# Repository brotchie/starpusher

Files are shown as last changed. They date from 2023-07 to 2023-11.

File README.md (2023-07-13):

# Starpusher

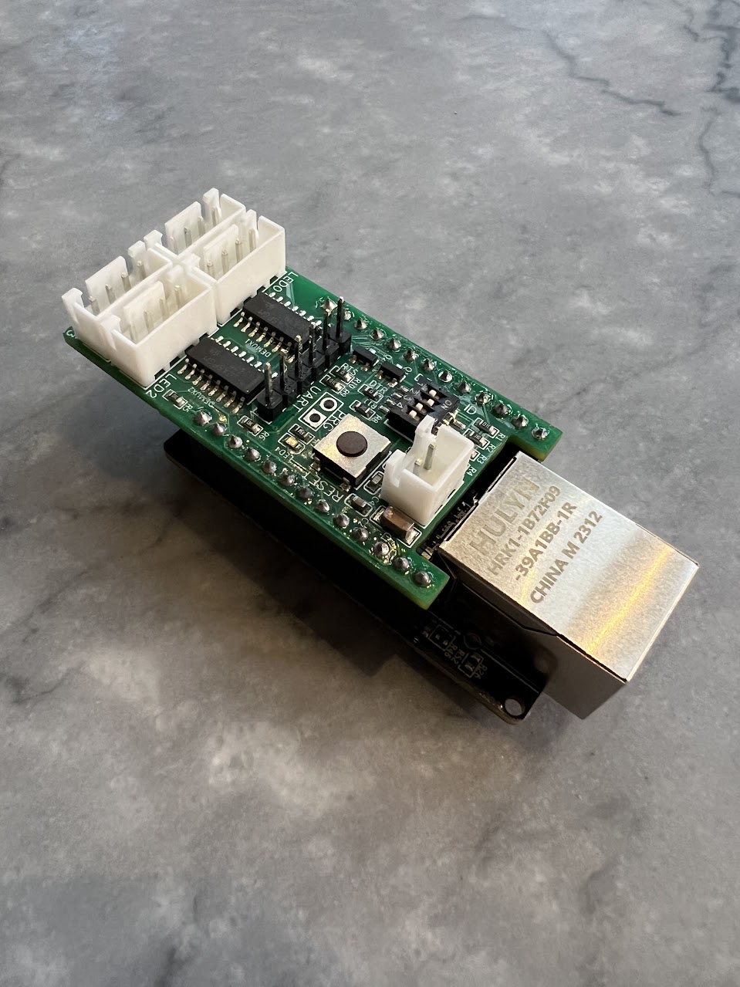
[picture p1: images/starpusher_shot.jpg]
Starshield


A Starpusher controls 4 x strips of APA102 LEDs (up to 420 LEDs per strip), taking LED information via UDP ethernet packets. We've tested it to run 4 x 420 LED strips at 60FPS with no glitches.

A Starpush comprises a [WT32 ETH01](https://www.amazon.com/EC-Buying-WT32-ETH01-Development-Bluetooth/dp/B09Z298QJQ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) with a custom-designed Starshield. The Starshield has a DIP switch that configures the Static IP address a given Starpusher uses and has headers for 4 LED strips.

See the comments in [main/starpusher.c](main/starpusher.c) for a codebase guide.

## Development Environment
Starshield code is built using the esp-idf toolchain.

1. Follow the steps in the [Standard Toolchain Setup Guide](https://docs.espressif.com/projects/esp-idf/en/latest/esp32/get-started/linux-macos-setup.html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),
2. Activate the esp-idf environment in a terminal (typically `$ get_idf` after following the setup guide,
3. Build the codebase `$ idf.py build`,
4. Connect your Starshield PCB to a WT32 ETH01 base board,
5. Connect a USB UART to the UART header on the Starshield,
6. Flash the Starpusher code onto the WT32 ETH01 by running `$ idf.py -p /dev/ttyUSB0 flash`
7. Monitor the WT32 ETH01's logs by running `$ idf.py -p /dev/ttyUSB0 monitor`

## REQUIRED: Configuring a new WT32 ETH01 for Starshield use
By default, on bootup, an ESP32 uses the value of pin IO12 to determine SPI Flash chip voltage. It has an internal pull-down so defaults to low (3.3V flash chip). If held high during bootup, then ESP32 treats Flash Chip voltage as 1.8V.

On our board we have a pull-up on IO12 since it's used to set the device ID via dip switch. The fix is to blow an eFuse on the ESP32 that fixes Flash chip voltage to 3.3v.

Do the following:

1. Set all dip switches on the ON position (this pulls IO12 low so it will actually boot), 
2. Run the following command to permanently burn the eFuse governing flash voltage so it's forced to 3.3V
   \
   `$ espefuse.py --do-not-confirm --port /dev/ttyUSBx set_flash_voltage 3.3V`
   \
   Replacing `/dev/ttyUSBx` with the port of your USB tty.

## Starshield

Schematics, gerber, BOM, and pick-and-place data for the Starshield V2 is in the `starshield` sub-folder.

### Board Overview

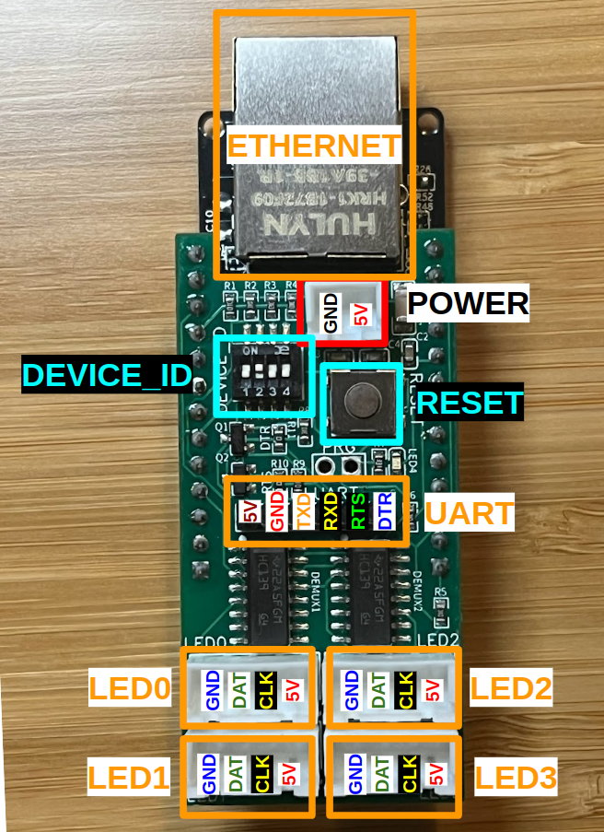
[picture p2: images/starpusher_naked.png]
Starshield Naked


### UART

The WT32 ETH01 that the Starshield sits sits on can be progammed via a USB UART (all development was done with a [DSD TECH SH-U09C5](https://www.amazon.com/gp/product/B07WX2DSVB/)) which has RTS and DTR pins so that ESP-IDF can program the ESP32 without having to manually fiddle with jumpers / manual resets.

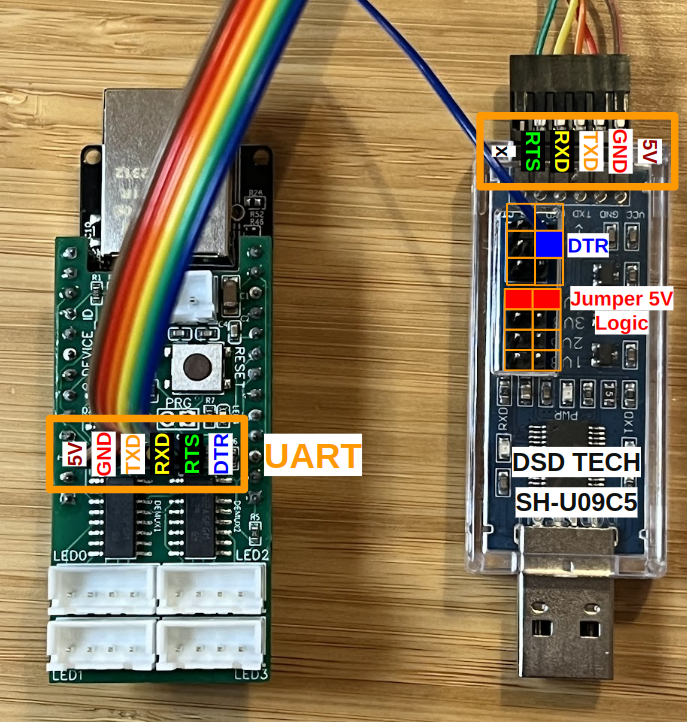
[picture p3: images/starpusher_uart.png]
Starshield UART


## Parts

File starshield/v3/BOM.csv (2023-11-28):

ID | Name | Designator | Footprint | Quantity | Manufacturer Part | Manufacturer | Supplier | Supplier Part | Price
1 | HDR-M-2.54_1x3 | BTNS | HDR-M-2.54_1X3 | 1 |  |  | LCSC | C180248 | 0.199
2 | 10kΩ | R12,R13,R1,R2,R3,R4,R6,R7,R10,R11 | R0402 | 10 | 0402WGF1002TCE | UNI-ROYAL(厚声) | LCSC | C25744 | 0.001
3 | XY303V-3.81-3P | PORT1,PORT2,PORT3,PORT4,PORT5,PORT6,PORT7,PORT8 | CONN-TH_XY303V-3.81-3P | 8 | XY303V-3.81-3P | XINLAIYA(新莱亚) | LCSC | C557684 | 0.168
4 | XY303V-3.81-2P | 12V | CONN-TH_XY303V-3.81-2P | 1 | XY303V-3.81-2P | XINLAIYA(新莱亚) | LCSC | C557683 | 0.113
5 | CD4504BM96 | LS1,LS2 | SOIC-16_L9.9-W3.9-P1.27-LS6.0-BL | 2 | CD4504BM96 | TI(德州仪器) | LCSC | C151885 | 0.395
6 | SN74HC595PWR | SR1,SR2 | TSSOP-16_L5.0-W4.4-P0.65-LS6.4-BL | 2 | SN74HC595PWR | TI(德州仪器) | LCSC | C273642 | 0.29
7 | 74HC165D,653 | SRID | SOIC-16_L9.9-W3.9-P1.27-LS6.0-BL | 1 | 74HC165D,653 | Nexperia(安世) | LCSC | C5613 | 0.155
8 | XL-5050RGBC-WS2812B | LED1 | LED-SMD_4P-L5.0-W5.0-BL_XL-5050RGBC | 1 | XL-5050RGBC-WS2812B | XINGLIGHT(成兴光) | LCSC | C2843785 | 0.044
9 | 1nF | C6 | C0402 | 1 | CC0402KRX7R9BB102 | YAGEO(国巨) | LCSC | C106205 | 0.001
10 | MT2492 | U6 | SOT-23-6_L2.9-W1.6-P0.95-LS2.8-BL | 1 | MT2492 | 西安航天民芯 | LCSC | C89358 | 0.051
11 | 22pF | BC1 | C0402 | 1 | 0402CG220J500NT | FH(风华) | LCSC | C1555 | 0.001
12 | 10uH | BL | IND-SMD_L4.4-W4.2 | 1 | FXL0420-100-M | cjiang(长江微电) | LCSC | C177242 | 0.111
13 | 110kΩ | BR1 | R0402 | 1 | RCT02110KJLF | HKR | LCSC | C174165
14 | 15kΩ | BR2 | R0402 | 1 | RMCF0402FT15K0 | SEI(Stackpole Electronics Inc.) | LCSC | C237741 | 0.003
15 | 22nF | BC2 | C0402 | 1 | CC0402KRX7R9BB223 | YAGEO(国巨) | LCSC | C107026 | 0.002
16 | 22uF | BCIN,BCOUT1,BCOUT2 | C0805 | 3 | CL21A226MAQNNNE | SAMSUNG(三星) | LCSC | C45783 | 0.026
17 | DSHP08TSGER_C3293147 | SW1 | SW-SMD_16P-L11.7-W5.4-P1.27-LS8.5 | 1 | DSHP08TSGER | 康深 | LCSC | C3293147 | 0.581
18 | Header-Male-2.54_1x6 | UART | HDR-TH_6P-P2.54-V-M-1 | 1 | 2.54-1x6P直针 | BOOMELE(博穆精密) | LCSC | C37208 | 0.028
19 | DTSL-61N-V-T/R | RESET | SW-SMD_4P-L6.2-W6.4-P4.00-LS7.2 | 1 | DTSL-61N-V-T/R | 圜达 | LCSC | C495902 | 0.055
20 | 10kΩ | R5,R8,R9 | R0603 | 3 | 0603WAF1002T5E | UNI-ROYAL(厚声) | LCSC | C25804 | 0.001
21 | MMBT2222A_C411776 | Q1,Q2 | SOT-23_L2.9-W1.3-P1.90-LS2.4-BR | 2 | MMBT2222A | PJSEMI(平晶微) | LCSC | C411776 | 0.019
22 | PM254-1-13-Z-8.5 | SH1,SH2 | HDR-TH_13P-P2.54-V-F | 2 | PM254-1-13-Z-8.5 | HCTL(华灿天禄) | LCSC | C2897376 | 0.204

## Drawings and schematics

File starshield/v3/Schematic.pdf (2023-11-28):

## Flash Circuit

## 12V to 5V Buck

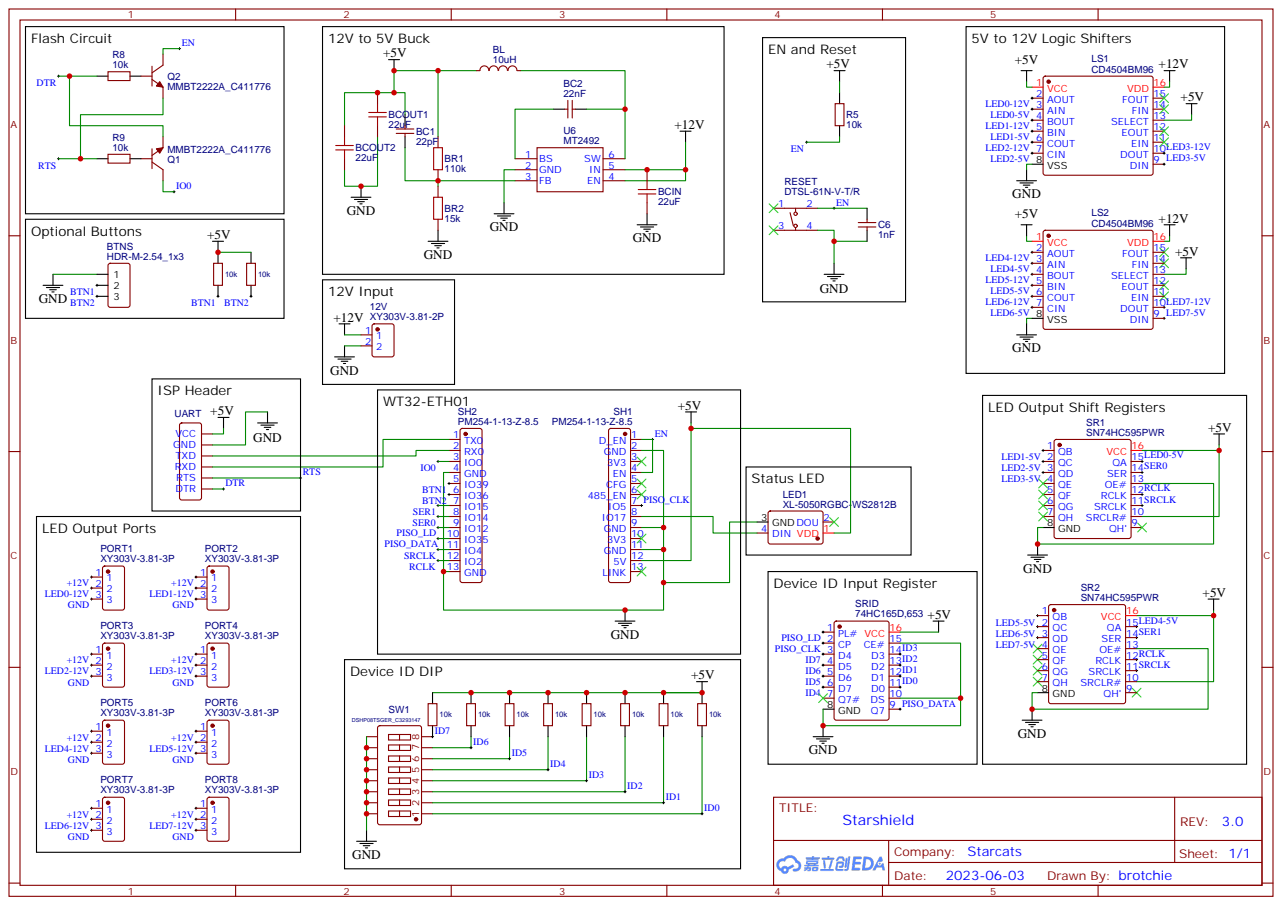
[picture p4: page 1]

LED Output Shift Registers

Device ID Input Register
DS 10 D0 11 D1 12 D2 13 D3 14 CE# 15 VCC 16

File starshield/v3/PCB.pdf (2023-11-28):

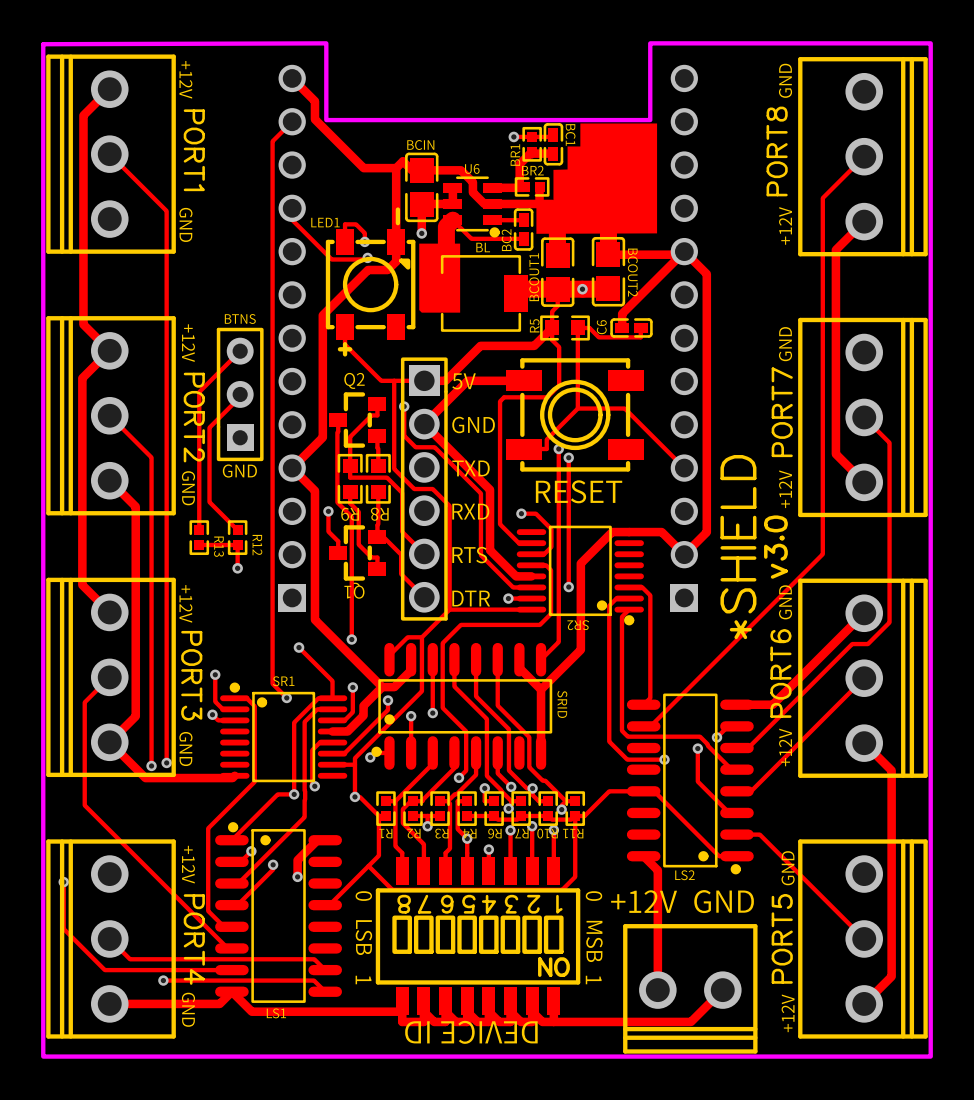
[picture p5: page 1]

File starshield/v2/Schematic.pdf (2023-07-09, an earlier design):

# 2Y2 10 2Y1 11 2Y0 12 2B 13 2A 14 2G# 15 VCC 16

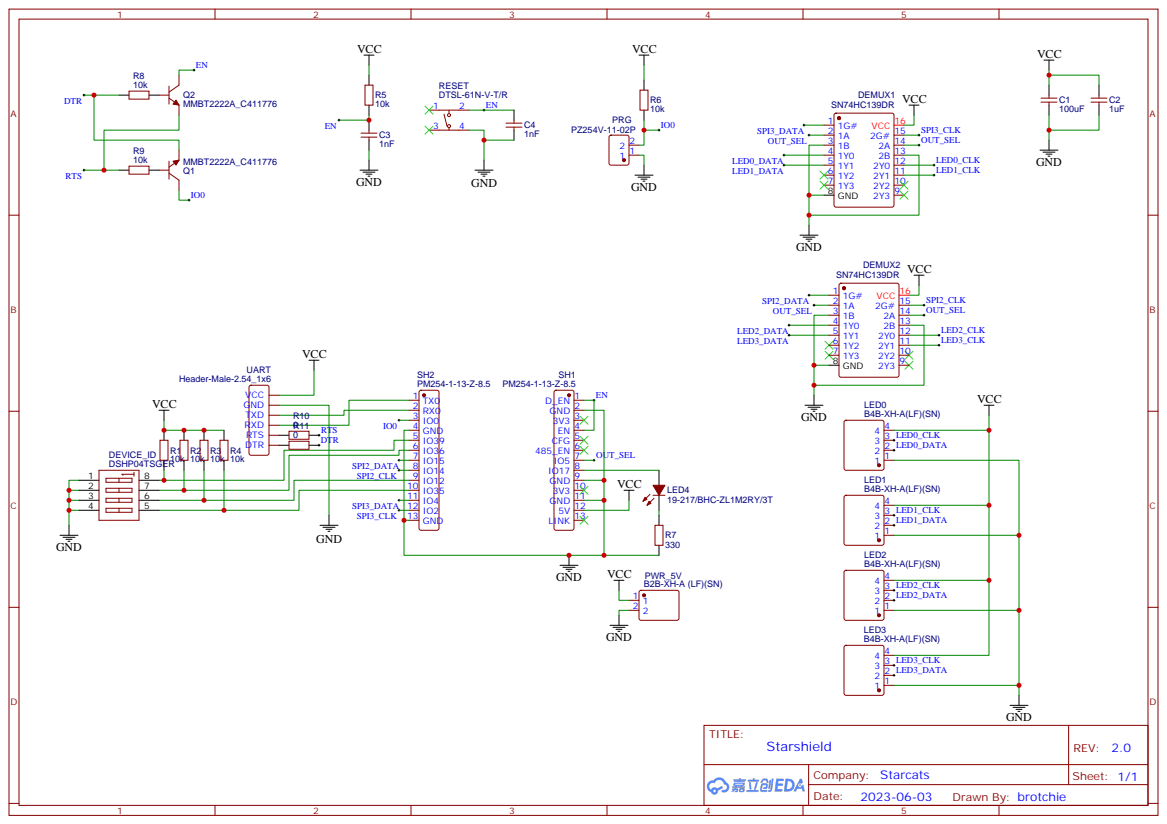
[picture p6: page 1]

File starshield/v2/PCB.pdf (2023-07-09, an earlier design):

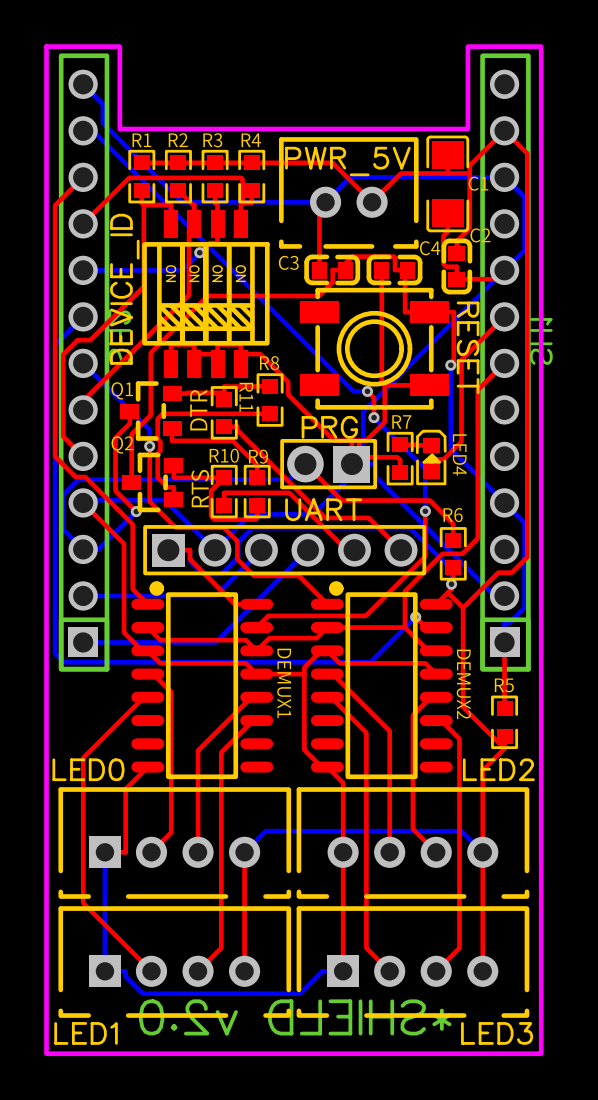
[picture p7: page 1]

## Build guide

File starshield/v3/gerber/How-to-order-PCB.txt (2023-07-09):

How to Order PCB

Please refer to:
https://docs.easyeda.com/en/PCB/Order-PCB

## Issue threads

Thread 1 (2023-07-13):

Add rainbow chase pattern for device id 14

brotchie, 2023-07-13:
Device id 15 is all white output, set device id 14 to be a 60 FPS rainbow chase to test changing pixel values.

When debugging attached LED strips it's valuable to see how they handle all-white at full intensity, but also how they handle full brightness patterns changing at a high rate with every pixel lit.

Closed 2023-11-27.

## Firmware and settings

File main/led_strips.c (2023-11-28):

#include <inttypes.h>
#include <string.h>

#include <driver/gpio.h>
#include <driver/spi_master.h>
#include <esp_heap_caps.h>
#include <esp_intr_alloc.h>
#include <esp_log.h>
#include <esp_timer.h>
#include <freertos/FreeRTOS.h>
#include <freertos/semphr.h>
#include <freertos/task.h>
#include <freertos/timers.h>

#include "color.h"
#include "led_strips.h"

static const char *TAG = "led_strips";

//#define BUILT_IN_ANIMATIONS
//#define PRINT_TIMING_DEBUG

#define PORT_COUNT 8

// 3 triangles with 55 LEDs on each side.
#define LEDS_PER_PORT 9 * 55

#define SPI_MAX_TRANSFER_SIZE 71282

// Drive SPI clock at 11Mhz. At 13Mhz it starts to glitch
// out a LED strip of length 495. At 10MHz is doesn't fit
// in the 13.3ms time bound for 60FPS.
#define SR_SRCLK_FREQUENCY SPI_MASTER_FREQ_11M

#define SR_SRCLK_GPIO GPIO_NUM_4

#define SR_SER0_GPIO GPIO_NUM_14
#define SR_SER1_GPIO GPIO_NUM_15
#define SR_RCLK_GPIO GPIO_NUM_2
// Unfortunately the SPI driver won't work in QUAD mode
// without mapping the data3 pin through GPIO (maybe
// there's a way around this?). We simply map the 4th
// SPI line to the CFG pin on the WT32-ETH0, which I
// don't think is used for anything.
#define SR_ZERO_GPIO GPIO_NUM_32

#define SR_SPI_HOST SPI2_HOST

static rgb_t pixel_buffer[PORT_COUNT][LEDS_PER_PORT];
static SemaphoreHandle_t pixel_buffer_mutex;

static spi_device_handle_t spi;
static uint8_t *dma_buffer = NULL;
static size_t dma_buffer_size;

static TaskHandle_t led_update_task_handle;

static TickType_t led_update_frequency = 60;

static uint32_t led_strips_animation_cycle = 0;

static uint64_t total_time_spent = 0;

void led_strips_spi_bus_initialize() {
  esp_err_t ret;
  spi_bus_config_t buscfg = {
      .data0_io_num = SR_RCLK_GPIO,
      .data1_io_num = SR_SER0_GPIO,
      .data2_io_num = SR_SER1_GPIO,
      .data3_io_num = SR_ZERO_GPIO,
      .sclk_io_num = SR_SRCLK_GPIO,
      .flags = SPICOMMON_BUSFLAG_QUAD | SPICOMMON_BUSFLAG_MASTER,
      .max_transfer_sz = SPI_MAX_TRANSFER_SIZE,
      // Pin all SPI ISR handling on CPU core 1.
      .isr_cpu_id = INTR_CPU_ID_1,
  };
  ret = spi_bus_initialize(SR_SPI_HOST, &buscfg, SPI_DMA_CH_AUTO);
  ESP_ERROR_CHECK(ret);

  spi_device_interface_config_t devcfg = {
      .clock_speed_hz = SR_SRCLK_FREQUENCY,
      .spics_io_num = -1,
      .queue_size = 1,
      // Don't need to receive SPI.
      .flags = SPI_DEVICE_HALFDUPLEX,
  };
  ret = spi_bus_add_device(SR_SPI_HOST, &devcfg, &spi);
  ESP_ERROR_CHECK(ret);
}

void led_strips_animation_tick() {
  for (uint16_t index = 0; index < LEDS_PER_PORT; index++) {
    rgb_t color = hsv_to_rgb(
        ((index + led_strips_animation_cycle) % 255) / 255.0f, 1.0, 1.0);
    for (uint8_t port = 0; port < PORT_COUNT; port++) {
      pixel_buffer[port][index] = color;
    }
  }
}

// Here we've pre-calculated the interleaving of all possible bytes into the
// packed format for quad-SPI DMA. This trades off memory (512 bytes) to save
// a bunch of shift and masking operations.
//
// These values also include bits for the shift register clock signal on SPI
// DATA0 and the empty last channel of quad-SPI on SPI DATA3.
static const uint16_t interleave_table_little_endian[256] = {
    0x0010, 0x0410, 0x4010, 0x4410, 0x0014, 0x0414, 0x4014, 0x4414, 0x0050,
    0x0450, 0x4050, 0x4450, 0x0054, 0x0454, 0x4054, 0x4454, 0x0210, 0x0610,
    0x4210, 0x4610, 0x0214, 0x0614, 0x4214, 0x4614, 0x0250, 0x0650, 0x4250,
    0x4650, 0x0254, 0x0654, 0x4254, 0x4654, 0x2010, 0x2410, 0x6010, 0x6410,
    0x2014, 0x2414, 0x6014, 0x6414, 0x2050, 0x2450, 0x6050, 0x6450, 0x2054,
    0x2454, 0x6054, 0x6454, 0x2210, 0x2610, 0x6210, 0x6610, 0x2214, 0x2614,
    0x6214, 0x6614, 0x2250, 0x2650, 0x6250, 0x6650, 0x2254, 0x2654, 0x6254,
    0x6654, 0x0012, 0x0412, 0x4012, 0x4412, 0x0016, 0x0416, 0x4016, 0x4416,
    0x0052, 0x0452, 0x4052, 0x4452, 0x0056, 0x0456, 0x4056, 0x4456, 0x0212,
    0x0612, 0x4212, 0x4612, 0x0216, 0x0616, 0x4216, 0x4616, 0x0252, 0x0652,
    0x4252, 0x4652, 0x0256, 0x0656, 0x4256, 0x4656, 0x2012, 0x2412, 0x6012,
    0x6412, 0x2016, 0x2416, 0x6016, 0x6416, 0x2052, 0x2452, 0x6052, 0x6452,
    0x2056, 0x2456, 0x6056, 0x6456, 0x2212, 0x2612, 0x6212, 0x6612, 0x2216,
    0x2616, 0x6216, 0x6616, 0x2252, 0x2652, 0x6252, 0x6652, 0x2256, 0x2656,
    0x6256, 0x6656, 0x0030, 0x0430, 0x4030, 0x4430, 0x0034, 0x0434, 0x4034,
    0x4434, 0x0070, 0x0470, 0x4070, 0x4470, 0x0074, 0x0474, 0x4074, 0x4474,
    0x0230, 0x0630, 0x4230, 0x4630, 0x0234, 0x0634, 0x4234, 0x4634, 0x0270,
    0x0670, 0x4270, 0x4670, 0x0274, 0x0674, 0x4274, 0x4674, 0x2030, 0x2430,
    0x6030, 0x6430, 0x2034, 0x2434, 0x6034, 0x6434, 0x2070, 0x2470, 0x6070,
    0x6470, 0x2074, 0x2474, 0x6074, 0x6474, 0x2230, 0x2630, 0x6230, 0x6630,
    0x2234, 0x2634, 0x6234, 0x6634, 0x2270, 0x2670, 0x6270, 0x6670, 0x2274,
    0x2674, 0x6274, 0x6674, 0x0032, 0x0432, 0x4032, 0x4432, 0x0036, 0x0436,
    0x4036, 0x4436, 0x0072, 0x0472, 0x4072, 0x4472, 0x0076, 0x0476, 0x4076,
    0x4476, 0x0232, 0x0632, 0x4232, 0x4632, 0x0236, 0x0636, 0x4236, 0x4636,
    0x0272, 0x0672, 0x4272, 0x4672, 0x0276, 0x0676, 0x4276, 0x4676, 0x2032,
    0x2432, 0x6032, 0x6432, 0x2036, 0x2436, 0x6036, 0x6436, 0x2072, 0x2472,
    0x6072, 0x6472, 0x2076, 0x2476, 0x6076, 0x6476, 0x2232, 0x2632, 0x6232,
    0x6632, 0x2236, 0x2636, 0x6236, 0x6636, 0x2272, 0x2672, 0x6272, 0x6672,
    0x2276, 0x2676, 0x6276, 0x6676};

#define INTERLEAVE(q, out)                                                     \
  *(uint16_t *)(out) = interleave_table_little_endian[q];

void init_dma_buffer(uint8_t *out, size_t count) {
  // Only the middle bit of each physical bit on the wire changes. The
  // first and last bit are always 1 and 0 respectively.
  for (size_t i = 0; i < 3 * count; i++) {
    INTERLEAVE(0xff, out);
    out += 2;
    INTERLEAVE(0x00, out);
    out += 2;
    INTERLEAVE(0x00, out);
    out += 2;
  }
}

void led_strips_initialize() {
  pixel_buffer_mutex = xSemaphoreCreateMutex();
  led_strips_spi_bus_initialize();
  // Initially set all colors to black.
  if (xSemaphoreTake(pixel_buffer_mutex, portMAX_DELAY) == pdTRUE) {
    memset(pixel_buffer, 0, sizeof(rgb_t) * LEDS_PER_PORT * PORT_COUNT);
    xSemaphoreGive(pixel_buffer_mutex);
  }
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

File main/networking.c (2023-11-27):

#include <esp_eth.h>
#include <esp_event.h>
#include <esp_log.h>
#include <esp_netif.h>
#include <esp_timer.h>
#include <freertos/FreeRTOS.h>
#include <freertos/task.h>
#include <freertos/timers.h>
#include <lwip/err.h>
#include <lwip/ip4_addr.h>
#include <lwip/netdb.h>
#include <lwip/sockets.h>
#include <lwip/sys.h>
#include <stdbool.h>

#include "common.h"
#include "indicator_led.h"
#include "networking.h"
#include "udp_protocol.h"

static const char *TAG = "networking";

#define WT32_ETH01_PHY_ADDR 1
#define WT32_ETH01_RESET_GPIO_NUM 16

#define MAX_UDP_PACKET_SIZE 1472
#define LISTEN_UDP_PORT 6868

#define DISCOVERY_MULTICAST_GROUP "239.10.11.12"
#define DISCOVERY_MULTICAST_PORT 21059
#define DISCOVERY_MULTICAST_TTL 5
#define DISCOVERY_BROADCAST_INTERVAL_MILLIS 1000

#define WATCHDOG_INTERVAL_MILLIS 5000

static rgb_t watchdog_tripped_led_color = {.r = 128, .g = 0, .b = 0};
static rgb_t networking_ok_led_color = {.r = 0, .g = 128, .b = 128};
static rgb_t udp_ok_led_color = {.r = 0, .g = 128, .b = 0};
static rgb_t networking_down_led_color = {.r = 128, .g = 0, .b = 128};

static TimerHandle_t udp_watchdog_timer;
static TimerHandle_t udp_discovery_timer;

static uint8_t device_id;

static bool first_udp_packet_received = false;

void create_static_ip_from_device_id(uint8_t device_id,
                                     char *buffer,
                                     size_t size) {
  snprintf(buffer, size, "10.1.1.%d", device_id);
}

static void eth_event_handler(void *arg,
                              esp_event_base_t event_base,
                              int32_t event_id,
                              void *event_data) {
  uint8_t mac_addr[6] = {0};
  /* we can get the ethernet driver handle from event data */
  esp_eth_handle_t eth_handle = *(esp_eth_handle_t *)event_data;

  switch (event_id) {
  case ETHERNET_EVENT_CONNECTED:
    esp_eth_ioctl(eth_handle, ETH_CMD_G_MAC_ADDR, mac_addr);
    ESP_LOGI(TAG, "Ethernet Link: UP");
    ESP_LOGI(TAG,
             "Ethernet HW Addr %02x:%02x:%02x:%02x:%02x:%02x",
             mac_addr[0],
             mac_addr[1],
             mac_addr[2],
             mac_addr[3],
             mac_addr[4],
             mac_addr[5]);
    indicator_led_set(networking_ok_led_color);
    break;
  case ETHERNET_EVENT_DISCONNECTED:
    ESP_LOGI(TAG, "Ethernet Link: DOWN");
    indicator_led_set(networking_down_led_color);
    break;
  case ETHERNET_EVENT_START:
    ESP_LOGI(TAG, "Ethernet: STARTED");
    break;
  case ETHERNET_EVENT_STOP:
    ESP_LOGI(TAG, "Ethernet: STOPPED");
    break;
  default:
    break;
  }
}

/** Event handler for IP_EVENT_ETH_GOT_IP */
static void got_ip_event_handler(void *arg,
                                 esp_event_base_t event_base,
                                 int32_t event_id,
                                 void *event_data) {
  ip_event_got_ip_t *event = (ip_event_got_ip_t *)event_data;
  const esp_netif_ip_info_t *ip_info = &event->ip_info;

  ESP_LOGI(TAG, "Ethernet Got IP Address");
  ESP_LOGI(TAG, "~~~~~~~~~~~");
  ESP_LOGI(TAG, "ETHIP:" IPSTR, IP2STR(&ip_info->ip));
  ESP_LOGI(TAG, "ETHMASK:" IPSTR, IP2STR(&ip_info->netmask));
  ESP_LOGI(TAG, "ETHGW:" IPSTR, IP2STR(&ip_info->gw));
  ESP_LOGI(TAG, "~~~~~~~~~~~");
}

static void set_static_ip(esp_netif_t *netif, char *ip_address) {
  if (esp_netif_dhcpc_stop(netif) != ESP_OK) {
    ESP_LOGE(TAG, "Failed to stop dhcp client");
    return;
  }
  esp_netif_ip_info_t ip;
  memset(&ip, 0, sizeof(esp_netif_ip_info_t));
  ip.ip.addr = ipaddr_addr(ip_address);
  ip.netmask.addr = ipaddr_addr("255.255.255.0");
  ip.gw.addr = ipaddr_addr("10.1.1.1");
  if (esp_netif_set_ip_info(netif, &ip) != ESP_OK) {
    ESP_LOGE(TAG, "Failed to set ip info");
    return;
  }
}

static void udp_watchdog_callback(TimerHandle_t xTimer) {
  ESP_LOGE(TAG, "UDP watchdog tripped");
  if (first_udp_packet_received) {
    indicator_led_set(watchdog_tripped_led_color);
  }
}

static void udp_discovery_callback(TimerHandle_t xTimer) {
  struct sockaddr_in saddr = {0};
  int sock = -1;
  int err = 0;

  char message[7] = {'*', 'D', device_id, 10, 1, 1, device_id};

  sock = socket(AF_INET, SOCK_DGRAM, IPPROTO_IP);
  if (sock < 0) {
    ESP_LOGE(TAG, "Failed to create socket. Error %d", errno);
    return;
  }

  saddr.sin_family = AF_INET;
  saddr.sin_port = htons(DISCOVERY_MULTICAST_PORT);
  saddr.sin_addr.s_addr = inet_addr(DISCOVERY_MULTICAST_GROUP);

  err = sendto(sock,
               message,
               sizeof(message),
               0,
               (struct sockaddr *)&saddr,
               sizeof(saddr));
  if (err < 0) {
    ESP_LOGE(TAG, "Failed to send to socket. Error %d", errno);
    return;
  }
  close(sock);
}

static void udp_server_task(void *pvParameters) {
  uint8_t rx_buffer[MAX_UDP_PACKET_SIZE];
  struct sockaddr_storage source_addr; // Large enough for both IPv4 or IPv6
  socklen_t socklen = sizeof(source_addr);

  struct sockaddr_in dest_addr;
  dest_addr.sin_addr.s_addr = htonl(INADDR_ANY);
  dest_addr.sin_family = AF_INET;
  dest_addr.sin_port = htons(LISTEN_UDP_PORT);

  while (1) {
    int sock = socket(AF_INET, SOCK_DGRAM, IPPROTO_IP);
    if (sock < 0) {
      ESP_LOGE(TAG, "Unable to create socket: errno %d", errno);
      break;
    }
    ESP_LOGI(TAG, "Socket created");

    int err = bind(sock, (struct sockaddr *)&dest_addr, sizeof(dest_addr));
    if (err < 0) {
      ESP_LOGE(TAG, "Socket unable to bind: errno %d", errno);
    }
    ESP_LOGI(TAG, "Socket bound, port %d", LISTEN_UDP_PORT);
    while (1) {
      ssize_t size = recvfrom(sock,
                              rx_buffer,
                              sizeof(rx_buffer),
                              0,
                              (struct sockaddr *)&source_addr,
                              &socklen);
      if (size < 0) {
        ESP_LOGE(TAG, "recvfrom failed: errno %d", errno);
        break;
      } else {
        if (!first_udp_packet_received) {
          first_udp_packet_received = true;
          indicator_led_set(udp_ok_led_color);
        }
        if (!xTimerIsTimerActive(udp_watchdog_timer)) {
          ESP_LOGI(TAG, "UDP watchdog reset");
          indicator_led_set(udp_ok_led_color);
        }
        xTimerReset(udp_watchdog_timer, 0);

        process_udp_packet(rx_buffer, size);
      }
    }
    if (sock != -1) {
      ESP_LOGE(TAG, "Shutting down socket and restarting...");
      shutdown(sock, 0);
      close(sock);
    }
  }
  vTaskDelete(NULL);
}
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

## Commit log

2023-07-09 Add PCB fabrication info.
    [BOM.csv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]
2023-07-10 Update to run networking on CPU0 and LED updates on CPU1.
2023-07-13 Add test pattern for device id 15.
    If all DIP switches are on, then output full power all white.
    Modified buffered_led_strips_reset to accept r, g, b, w arguments
    to reset buffer to a specific color.
    [networking.c]
2023-08-02 Add pygame-based LED strip simulator.
2023-08-22 Add button handling to viz.
2023-09-29 Add library to read 8-bit device id using 74HC165.
2023-11-28 Add Starshield V3 PCB designs.
    [BOM.csv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]
2023-11-28 Improve comments to better describe interleaving and DMA buffer sizing.
